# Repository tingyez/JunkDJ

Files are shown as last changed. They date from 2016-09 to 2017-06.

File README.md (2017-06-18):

# JunkDJ
JunkDJ is a recycled music station consists of two main components-a rotary phone and an instrumental keypad. The rotary phone plays background music and the instrumental keypad plays light and sound effects. JunkDJ is made of components from old and obsolete devices such as a rotary phone and an old home telephone combining with modern components such as micro-controllers (Arduino), an MP3 player shield, an LED ring, and Bluetooth components.This project aims to 

build a device that everyone can enjoy playing and making music without knowledge around music and technology. It can also be used for reflecting and expressing feelings of users. 

Team members:  
* Merel Vermeeren  
* Peng Gao  
* Pruek Laochaiyapruek  
* TingyeZhong  

This project was from the Physical Interaction Design and Realization course at KTH (2016).

Read more about the project here: [https://junkdjs.wordpress.com](http://junkdjs.wordpress.com)

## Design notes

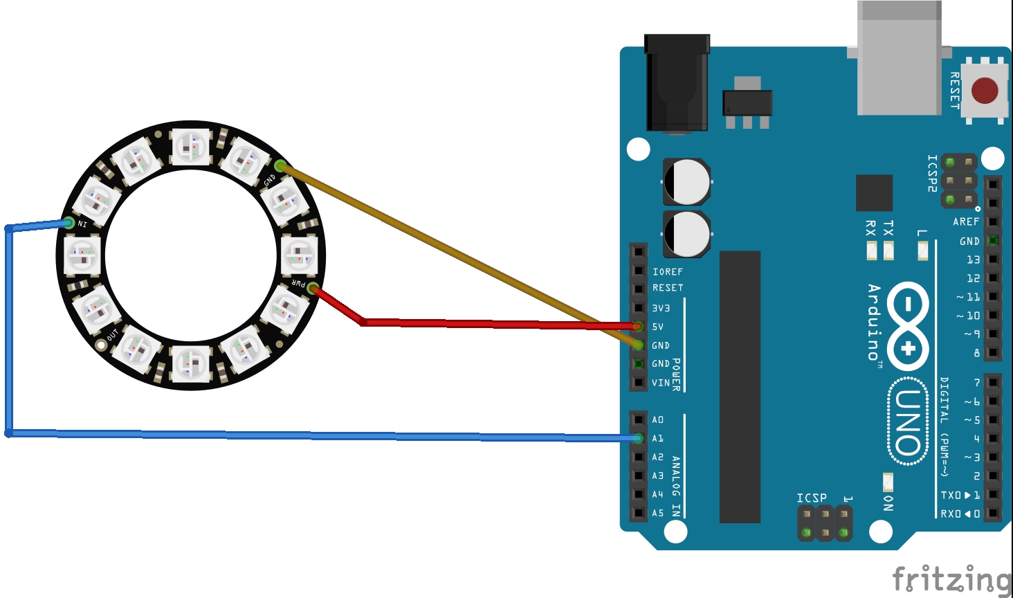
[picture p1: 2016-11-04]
fritzing/ring_bb.jpg

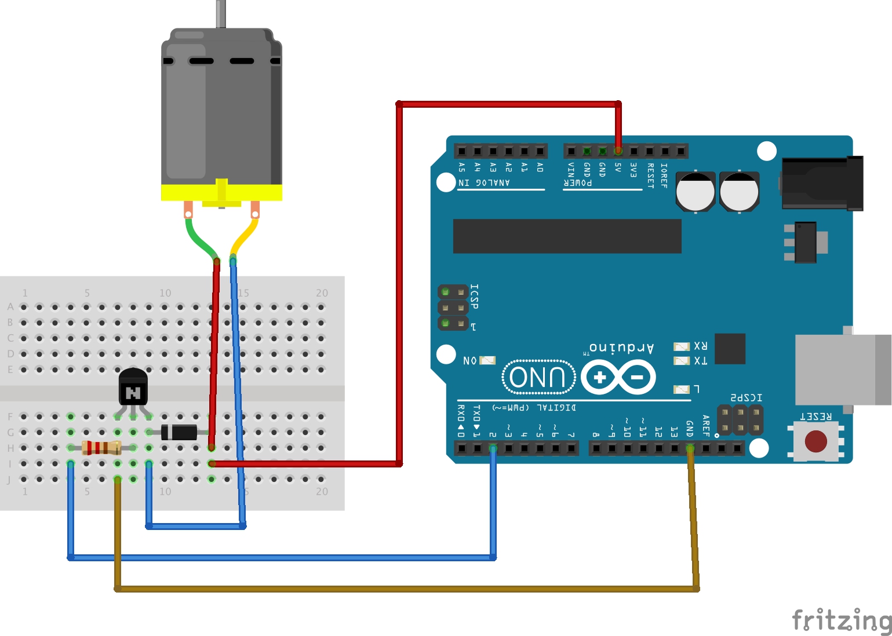
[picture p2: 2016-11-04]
fritzing/bell_bb.jpg

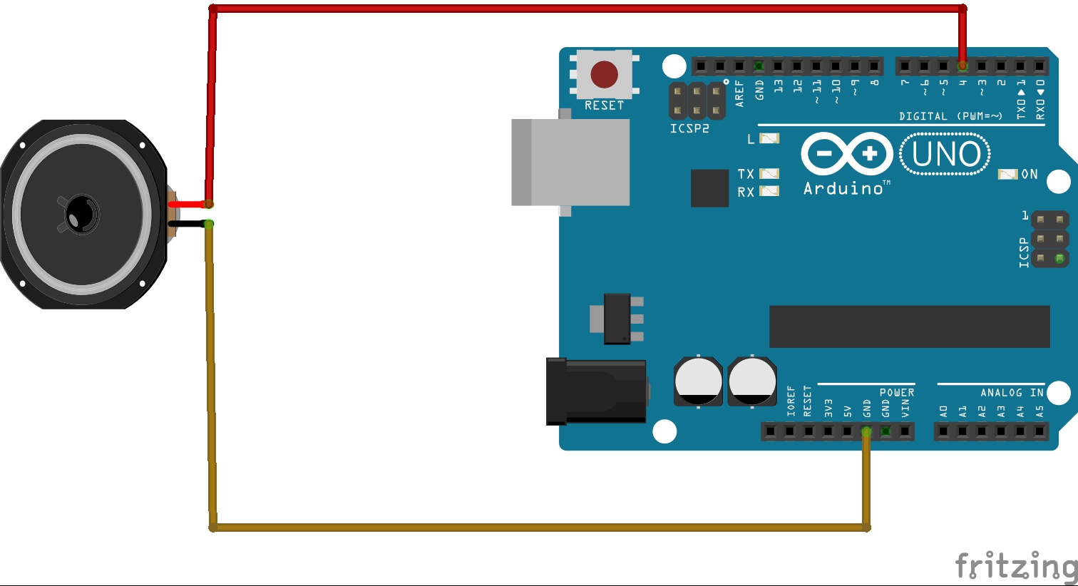
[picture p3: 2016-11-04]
fritzing/speaker_bb.jpg

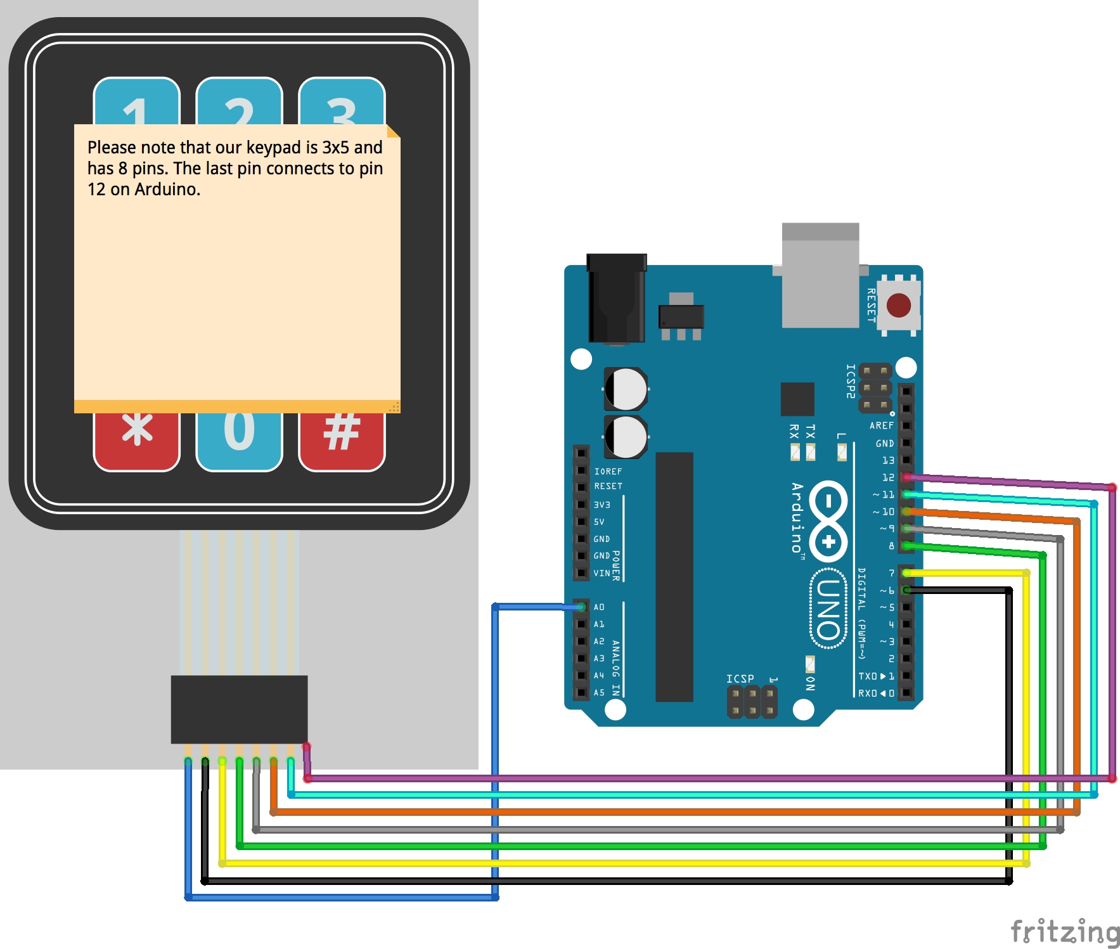
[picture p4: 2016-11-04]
fritzing/keypad_bb.jpg

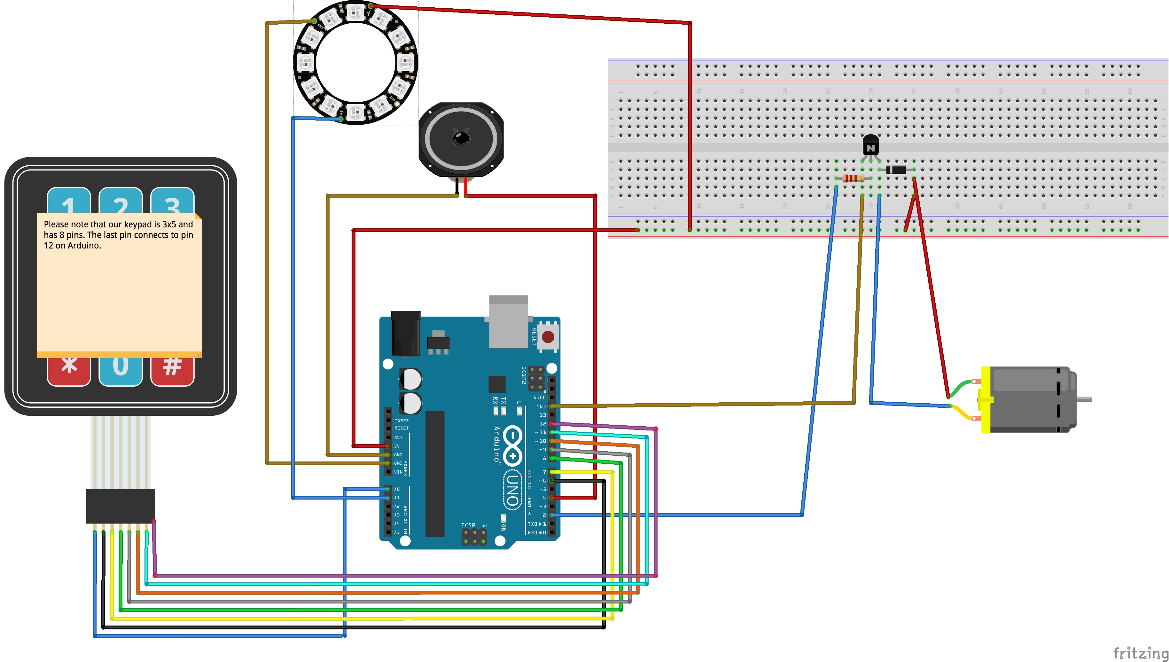
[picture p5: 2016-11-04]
fritzing/all_bb.jpg

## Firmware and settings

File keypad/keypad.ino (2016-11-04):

/*  FROM http://playground.arduino.cc/Main/KeypadTutorial
 *  
 *  MORE EXAMPLES http://playground.arduino.cc/Code/Keypad#Example
 *   
 *   Keypadtest.pde
 *
 *  Demonstrate the simplest use of the  keypad library.
 *
 *  The first step is to connect your keypad to the
 *  Arduino  using the pin numbers listed below in
 *  rowPins[] and colPins[]. If you want to use different
 *  pins then  you  can  change  the  numbers below to
 *  match your setup.
 *
 */
#include <Keypad.h>
#include "pitches.h"


#include <Adafruit_NeoPixel.h>
#ifdef __AVR__
  #include <avr/power.h>
#endif
#define ringPin A1
// How many NeoPixels are attached to the Arduino? (0-11)
#define ringPixels 12

// Parameter 1 = number of pixels in strip
// Parameter 2 = Arduino pin number (most are valid)
// Parameter 3 = pixel type flags, add together as needed:
//   NEO_KHZ800  800 KHz bitstream (most NeoPixel products w/WS2812 LEDs)
//   NEO_KHZ400  400 KHz (classic 'v1' (not v2) FLORA pixels, WS2811 drivers)
//   NEO_GRB     Pixels are wired for GRB bitstream (most NeoPixel products)
//   NEO_RGB     Pixels are wired for RGB bitstream (v1 FLORA pixels, not v2)
//   NEO_RGBW    Pixels are wired for RGBW bitstream (NeoPixel RGBW products)
Adafruit_NeoPixel pixels = Adafruit_NeoPixel(ringPixels, ringPin, NEO_GRB + NEO_KHZ800);


const byte aROWS = 4; // Four rows
const byte aCOLS = 3; // Three columns
// Define the Keymap
char akeys[aROWS][aCOLS] = {
  {'1','2','3'},
  {'4','5','6'},
  {'7','8','9'},
  {'#','0','*'}
};

const byte bROWS = 1; // + one rows
const byte bCOLS = 3; // Three columns
// Define the Keymap
char bkeys[bROWS][bCOLS] = {
  {'a','b','c'}
};


// Connect keypad ROW0, ROW1, ROW2 and ROW3 to these Arduino pins.
//byte rowPins[ROWS] = { 9, 8, 7, 6 };
// Connect keypad COL0, COL1 and COL2 to these Arduino pins.
//byte colPins[COLS] = { 12, 11, 10 }; 

// REMAPPED CONNECTION
byte arowPins[aROWS] = { 12, 7, 9, 10 };
byte acolPins[aCOLS] = { 11, 8, 6 }; 

byte browPins[aROWS] = { A0 };     //this one is not connected yet
byte bcolPins[aCOLS] = { 7, 9, 10 }; 


// Create the Keypad
Keypad kpdA = Keypad( makeKeymap(akeys), arowPins, acolPins, aROWS, aCOLS );
Keypad kpdB = Keypad( makeKeymap(bkeys), browPins, bcolPins, bROWS, bCOLS );


#define ledpin 13
int motorPin = 2;
int melodyPin = A2;

//Mario main theme melody
int melody[] = {
  NOTE_E7, NOTE_E7, 0, NOTE_E7,
  0, NOTE_C7, NOTE_E7, 0,
  NOTE_G7, 0, 0,  0,
  NOTE_G6, 0, 0, 0,
 
  NOTE_C7, 0, 0, NOTE_G6,
  0, 0, NOTE_E6, 0,
  0, NOTE_A6, 0, NOTE_B6,
  0, NOTE_AS6, NOTE_A6, 0,
 
  NOTE_G6, NOTE_E7, NOTE_G7,
  NOTE_A7, 0, NOTE_F7, NOTE_G7,
  0, NOTE_E7, 0, NOTE_C7,
  NOTE_D7, NOTE_B6, 0, 0,
 
  NOTE_C7, 0, 0, NOTE_G6,
  0, 0, NOTE_E6, 0,
  0, NOTE_A6, 0, NOTE_B6,
  0, NOTE_AS6, NOTE_A6, 0,
 
  NOTE_G6, NOTE_E7, NOTE_G7,
  NOTE_A7, 0, NOTE_F7, NOTE_G7,
  0, NOTE_E7, 0, NOTE_C7,
  NOTE_D7, NOTE_B6, 0, 0
};
//Mario main them tempo
int tempo[] = {
  12, 12, 12, 12,
  12, 12, 12, 12,
  12, 12, 12, 12,
  12, 12, 12, 12,
 
  12, 12, 12, 12,
  12, 12, 12, 12,
  12, 12, 12, 12,
  12, 12, 12, 12,
 
  9, 9, 9,
  12, 12, 12, 12,
  12, 12, 12, 12,
  12, 12, 12, 12,
 
  12, 12, 12, 12,
  12, 12, 12, 12,
  12, 12, 12, 12,
  12, 12, 12, 12,
 
  9, 9, 9,
  12, 12, 12, 12,
  12, 12, 12, 12,
  12, 12, 12, 12,
};
//Underworld melody
int underworld_melody[] = {
  NOTE_C4, NOTE_C5, NOTE_A3, NOTE_A4,
  NOTE_AS3, NOTE_AS4, 0,
  0,
  NOTE_C4, NOTE_C5, NOTE_A3, NOTE_A4,
  NOTE_AS3, NOTE_AS4, 0,
  0,
  NOTE_F3, NOTE_F4, NOTE_D3, NOTE_D4,
  NOTE_DS3, NOTE_DS4, 0,
  0,
  NOTE_F3, NOTE_F4, NOTE_D3, NOTE_D4,
  NOTE_DS3, NOTE_DS4, 0,
  0, NOTE_DS4, NOTE_CS4, NOTE_D4,
  NOTE_CS4, NOTE_DS4,
  NOTE_DS4, NOTE_GS3,
  NOTE_G3, NOTE_CS4,
  NOTE_C4, NOTE_FS4, NOTE_F4, NOTE_E3, NOTE_AS4, NOTE_A4,
  NOTE_GS4, NOTE_DS4, NOTE_B3,
  NOTE_AS3, NOTE_A3, NOTE_GS3,
  0, 0, 0
};
//Underwolrd tempo
int underworld_tempo[] = {
  12, 12, 12, 12,
  12, 12, 6,
  3,
  12, 12, 12, 12,
  12, 12, 6,
  3,
  12, 12, 12, 12,
  12, 12, 6,
  3,
  12, 12, 12, 12,
  12, 12, 6,
  6, 18, 18, 18,
  6, 6,
  6, 6,
  6, 6,
  18, 18, 18, 18, 18, 18,
  10, 10, 10,
  10, 10, 10,
  3, 3, 3
};

int count=0;

bool ringOn = false;


//////////////////////////////////// BLUETOOTH

#include <SoftwareSerial.h>
SoftwareSerial BTSerial(A4, A5); // RX | TX

char c = ' ';

//////////////////////////////////// END BLUETOOTH



void setup()
{
  pinMode(ledpin,OUTPUT);
  pinMode(motorPin, OUTPUT);
  digitalWrite(ledpin, HIGH);
  Serial.begin(9600);

  while (! Serial);
  Serial.println("Speed 0 to 255");


  pixels.begin();
  pixels.show(); // Initialize all pixels to 'off'


  ///////////////////////////////////////////////// BLUETOOTH
  Serial.println("Arduino with HC-06 is ready");
 
  // HC-06 default baud rate is 9600
  BTSerial.begin(9600);  
  Serial.println("BTserial started at 9600");
  ///////////////////////////////////////////////// END BLUETOOTH
}

void loop()
{
  ///////////////////////////////////////////////// BLUETOOTH
  // Keep reading from HC-06 and send to Arduino Serial Monitor
  if (BTSerial.available()){
    c = BTSerial.read();
    Serial.write(c);
  }
  // Keep reading from Arduino Serial Monitor and send to HC-06
  if (Serial.available()){
    c = Serial.read();
    BTSerial.write(c);
  }
  ///////////////////////////////////////////////// END BLUETOOTH
  
//  if (Serial.available())
//  {
//    int speed = Serial.parseInt();
//    if (speed >= 0 && speed <= 255)
//    {
//      analogWrite(motorPin, speed);
//    }
//  }
  

  int noteDuration = 1000/8;
   
  char keyA = kpdA.getKey();
  char keyB = kpdB.getKey();
  
//  int reading = digitalRead(key);

  
  if(keyA)  // Check for a valid key.
  {
//    Serial.println(reading);
    switch (keyA)
    {
      // to calculate the note duration, take one second 
      // divided by the note type.
      //e.g. quarter note = 1000 / 4, eighth note = 1000/8, etc.
      case '1':
        tone(melodyPin, NOTE_A3,noteDuration);
        Serial.println("1");
    
        lightRing(0, 6, pixels.Color(0,255,0), 200);
        
        break;
      case '2':
        tone(melodyPin, NOTE_B3,noteDuration);
        Serial.println("2");

        lightRing(1, 7, pixels.Color(255,0,0), 200); 
        
        break;
      case '3':
        tone(melodyPin, NOTE_C4,noteDuration);
        Serial.println("3");

        lightRing(2, 8, pixels.Color(255,0,255), 200);
        
        break;
      case '4':
        tone(melodyPin, NOTE_D4,noteDuration);
        Serial.println("4");

        lightRing(3, 9, pixels.Color(0,0,255), 200); 
        
        break;
      case '5':
        tone(melodyPin, NOTE_E4,noteDuration);
        Serial.println("5");

        lightRing(4, 10, pixels.Color(150,0,250), 200);
        
        break;
      case '6':
        tone(melodyPin, NOTE_F4,noteDuration);
        Serial.println("6");

        lightRing(5,11, pixels.Color(0,150,250), 200);
        
        break;
      case '7':
        tone(melodyPin, NOTE_G4,noteDuration);
        Serial.println("7");

        lightRing(6,0, pixels.Color(150,150,250), 200); 
        
        break;
      case '8':
        tone(melodyPin, NOTE_A4,noteDuration);
        Serial.println("8");
        
        lightRing(7, 1, pixels.Color(250,150,0), 200);
        
        break;
      case '9':
        tone(melodyPin, NOTE_B4,noteDuration);
        Serial.println("9");

        lightRing(8, 2, pixels.Color(100,150,100), 200); 
        
        break;
        
      case '0':
        tone(melodyPin, NOTE_C5,noteDuration);
        Serial.println("0");

        lightRing(9, 3, pixels.Color(200,100,50), 200); 
        
        break;
        
      case '*':
        Serial.println("*");
        tone(melodyPin, NOTE_A3,noteDuration);
        delay(125);
        tone(melodyPin, NOTE_B3,noteDuration);
        delay(125);
        tone(melodyPin, NOTE_C3,noteDuration);

        if (!ringOn){
          ringOn = true;
          rainbowCycle(20);
        } else{
          ringOn = false;
          killRing();
        }
        break;
      case '#':
        Serial.println("#");
        tone(melodyPin, NOTE_F3,noteDuration);
        delay(125);
        tone(melodyPin, NOTE_E3,noteDuration);
        delay(125);
        tone(melodyPin, NOTE_D3,noteDuration);

        if (!ringOn){
          ringOn = true;
          rainbowCycle2(20);
        } else{
          ringOn = false;
          killRing();
        }
        break;
      default:
        Serial.println(keyA);

    }
   
  }
  
  

  if (keyB){

    switch(keyB){

      case 'a':

        marioRainbowCycle1();
         
        Serial.println(" 'Mario Theme'");
//        int size = sizeof(melody) / sizeof(int);
        for (int thisNote = 0; thisNote < 12; thisNote++) {
          int noteDuration = 1000 / tempo[thisNote];
          tone(melodyPin, melody[thisNote], noteDuration);
          int pauseBetweenNotes = noteDuration * 1.30;
          delay(pauseBetweenNotes);
     
          // stop the tone playing:
          tone(4, 0, noteDuration);
        }

        marioRainbowCycle2();
        
        break;
      case 'b':
        Serial.println("b");
        
        count++;
        if (count%2==1){
            analogWrite(motorPin, 200);
            ringOn = true;
            rainbowCycle(0);
        }
        else{
            analogWrite(motorPin, 0);
            ringOn = false;
            killRing();
        }
        break;
      case 'c':
        Serial.println("c");

        marioRainbowCycle2();
        
        //        int size = sizeof(underworld_melody) / sizeof(int);
        for (int thisNote = 0; thisNote < 8; thisNote++) {
          // to calculate the note duration, take one second
          // divided by the note type.
          //e.g. quarter note = 1000 / 4, eighth note = 1000/8, etc.
          int noteDuration = 1000 / underworld_tempo[thisNote];
     
          tone(melodyPin, underworld_melody[thisNote], noteDuration);
     
          // to distinguish the notes, set a minimum time between them.
          // the note's duration + 30% seems to work well:
          int pauseBetweenNotes = noteDuration * 1.30;
          delay(pauseBetweenNotes);
     
          // stop the tone playing:
          tone(melodyPin, 0, noteDuration);
        }

        marioRainbowCycle1();
         
        break;
      default:
        Serial.println(keyB);
    }
  }
   
}

void lightRing(uint8_t pos, uint8_t pos2, uint32_t color, uint8_t wait){
  // pixels.Color takes RGB values, from 0,0,0 up to 255,255,255
  pixels.setPixelColor(pos, color); 
  pixels.setPixelColor(pos2, color); 
  pixels.show(); // This sends the updated pixel color to the hardware.
  delay (wait);
  pixels.setPixelColor(pos, 0); 
  pixels.setPixelColor(pos2, 0); 
  pixels.show();
}

void marioRainbowCycle1() {
  uint16_t i, j;

  for(j=0; j<1; j++) { // 5 cycles of all colors on wheel
    for(i=0; i< ringPixels; i++) {
      pixels.setPixelColor(i, Wheel(((i * 256 / ringPixels) + j) & 255));
      pixels.show();
      delay(20);
      pixels.setPixelColor(i, 0);
      pixels.show();
    }
  }
}

void marioRainbowCycle2() {
  uint16_t i, j;

  for(j=0; j<1; j++) { // 5 cycles of all colors on wheel
    for(i=ringPixels-1; i>= 0 & i < ringPixels; i--) {
      pixels.setPixelColor(i, Wheel(((i * 256 / ringPixels) + j) & 255));
      pixels.show();
      delay(20);
      pixels.setPixelColor(i, 0);
      pixels.show();
      Serial.println (i);
    }
  }
}

// Slightly different, this makes the rainbow equally distributed throughout
void rainbowCycle(uint8_t wait) {
  uint16_t i, j;

  for(j=0; j<1; j++) { // 5 cycles of all colors on wheel
    for(i=0; i< ringPixels; i++) {
      pixels.setPixelColor(i, Wheel(((i * 256 / ringPixels) + j) & 255));
      pixels.show();
      delay(wait);
    }
  }
}

void rainbowCycle2(uint8_t wait) {
  uint16_t i, j;

  for(j=0; j<1; j++) { // 5 cycles of all colors on wheel
    for(i=ringPixels-1; i>= 0 & i < ringPixels; i--) {
      pixels.setPixelColor(i, Wheel(((i * 256 / ringPixels) + j) & 255));
      pixels.show();
      delay(wait);
    }
  }
}

// Input a value 0 to 255 to get a color value.
// The colours are a transition r - g - b - back to r.
uint32_t Wheel(byte WheelPos) {
  WheelPos = 255 - WheelPos;
  if(WheelPos < 85) {
    return pixels.Color(255 - WheelPos * 3, 0, WheelPos * 3);
  }
  if(WheelPos < 170) {
    WheelPos -= 85;
    return pixels.Color(0, WheelPos * 3, 255 - WheelPos * 3);
  }
  WheelPos -= 170;
  return pixels.Color(WheelPos * 3, 255 - WheelPos * 3, 0);
}

void killRing (){
  uint16_t i, j;

  for(j=0; j<1; j++) { // 5 cycles of all colors on wheel
    for(i=ringPixels-1; i>= 0 & i < ringPixels; i--) {
      pixels.setPixelColor(i, 0);
      pixels.show();
      delay(10);
    }
  }
}

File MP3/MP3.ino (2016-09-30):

/**
 * \file FilePlayer.ino
 *
 * \brief Example sketch of using the MP3Shield Arduino driver, with flexible list of files and formats
 * \remarks comments are implemented with Doxygen Markdown format
 *
 * \author Bill Porter
 * \author Michael P. Flaga
 *
 * This sketch listens for commands from a serial terminal (such as the Serial
 * Monitor in the Arduino IDE). Listening for either a single character menu
 * commands or an numeric strings of an index. Pointing to a music file, found
 * in the root of the SdCard, to be played. A list of index's and corresponding
 * files in the root can be listed out using the 'l' (little L) command.
 *
 * This sketch allows the various file formats to be played: mp3, aac, wma, wav,
 * fla & mid.
 *
 * This sketch behaves nearly identical to MP3Shield_Library_Demo.ino, but has
 * extra complicated loop() as to recieve string of characters to create the
 * file index. As the Serial Monitor is typically default with no CR or LF, this
 * sketch uses intercharacter time out as to determine when a full string has
 * has been entered to be processed.
 */

#include <SPI.h>

//Add the SdFat Libraries
#include <SdFat.h>
#include <SdFatUtil.h>

//and the MP3 Shield Library
#include <SFEMP3Shield.h>

// Below is not needed if interrupt driven. Safe to remove if not using.
#if defined(USE_MP3_REFILL_MEANS) && USE_MP3_REFILL_MEANS == USE_MP3_Timer1
  #include <TimerOne.h>
#elif defined(USE_MP3_REFILL_MEANS) && USE_MP3_REFILL_MEANS == USE_MP3_SimpleTimer
  #include <SimpleTimer.h>
#endif

/**
 * \brief Object instancing the SdFat library.
 *
 * principal object for handling all SdCard functions.
 */
SdFat sd;

/**
 * \brief Object instancing the SFEMP3Shield library.
 *
 * principal object for handling all the attributes, members and functions for the library.
 */
SFEMP3Shield MP3player;
int16_t last_ms_char; // milliseconds of last recieved character from Serial port.
int8_t buffer_pos; // next position to recieve character from Serial port.

//------------------------------------------------------------------------------
/**
 * \brief Setup the Arduino Chip's feature for our use.
 *
 * After Arduino's kernel has booted initialize basic features for this
 * application, such as Serial port and MP3player objects with .begin.
 * Along with displaying the Help Menu.
 *
 * \note returned Error codes are typically passed up from MP3player.
 * Whicn in turns creates and initializes the SdCard objects.
 *
 * \see
 * \ref Error_Codes
 */
  char buffer[6]; // 0-35K+null


// constants

int dialHasFinishedRotatingAfterMs = 100;
int debounceDelay = 10;
int needToPrint = 0;
int count;
int in = 2;
int lastState = LOW;
int trueState = LOW;
long lastStateChangeTime = 0;
int cleared = 0;

void setup() {

  uint8_t result; //result code from some function as to be tested at later time.

  Serial.begin(9600);
  Serial.println("Welcome to JunkDJ!");
  Serial.println("Please dail the phone to select the track");

  //Serial.print(F("F_CPU = "));
  //Serial.println(F_CPU);
  //Serial.print(F("Free RAM = ")); // available in Version 1.0 F() bases the string to into Flash, to use less SRAM.
  //Serial.print(FreeRam(), DEC);  // FreeRam() is provided by SdFatUtil.h
  //Serial.println(F(" Should be a base line of 1017, on ATmega328 when using INTx"));


  //Initialize the SdCard.
  if(!sd.begin(SD_SEL, SPI_FULL_SPEED)) sd.initErrorHalt();
  // depending upon your SdCard environment, SPI_HAVE_SPEED may work better.
  if(!sd.chdir("/")) sd.errorHalt("sd.chdir");

  //Initialize the MP3 Player Shield
  result = MP3player.begin();
  //check result, see readme for error codes.
  if(result != 0) {
    //Serial.print(F("Error code: "));
    //Serial.print(result);
    //Serial.println(F(" when trying to start MP3 player"));
    if( result == 6 ) {
      //Serial.println(F("Warning: patch file not found, skipping.")); // can be removed for space, if needed.
      //Serial.println(F("Use the \"d\" command to verify SdCard can be read")); // can be removed for space, if needed.
    }
  }

#if (0)
  // Typically not used by most shields, hence commented out.
  //Serial.println(F("Applying ADMixer patch."));
  if(MP3player.ADMixerLoad("admxster.053") == 0) {
    //Serial.println(F("Setting ADMixer Volume."));
    MP3player.ADMixerVol(-3);
  }
#endif

  // help();
  //last_ms_char = millis(); // stroke the inter character timeout.
  buffer_pos = 0; // start the command string at zero length.
  //parse_menu('l'); // display the list of files to play

}

//------------------------------------------------------------------------------
/**
 * \brief Main Loop the Arduino Chip
 *
 * This is called at the end of Arduino kernel's main loop before recycling.
 * And is where the user's serial input of bytes are read and analyzed by
 * parsed_menu.
 *
 * Additionally, if the means of refilling is not interrupt based then the
 * MP3player object is serviced with the availaible function.
 *
 * \note Actual examples of the libraries public functions are implemented in
 * the parse_menu() function.
 */
void loop() {
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

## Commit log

2016-09-28 dail-2
    only need two wires
2016-09-29 Keypad sample code
    FROM http://playground.arduino.cc/Main/KeypadTutorial
    MORE EXAMPLES http://playground.arduino.cc/Code/Keypad#Example
2016-09-30 fix the file name
    [dail--1.ino, dail--2.ino, keypad.ino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]
2016-09-30 use analog pin as input
2016-09-30 add sound to buttons
2016-10-03 use one button to control bell
2016-10-09 optimise LED ring codes
2016-10-13 update the light functions
    add lights to every buttons
2016-10-15 fritzing diagrams
    [all.fzz, bell.fzz, keypad.fzz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]
